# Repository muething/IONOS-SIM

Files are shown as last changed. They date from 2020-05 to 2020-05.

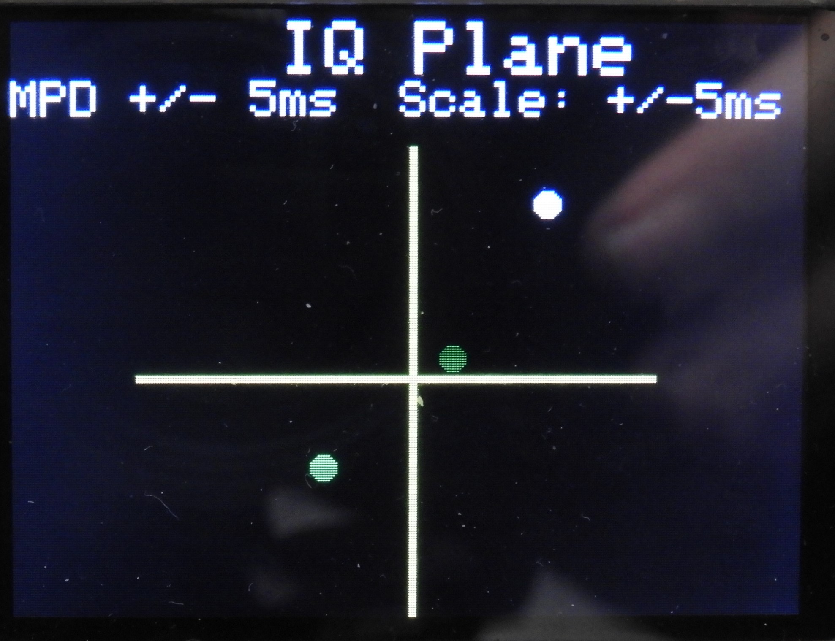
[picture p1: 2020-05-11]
IONOS_SIM_Channel_Simulator/Support Docs/DSCN1394.jpg

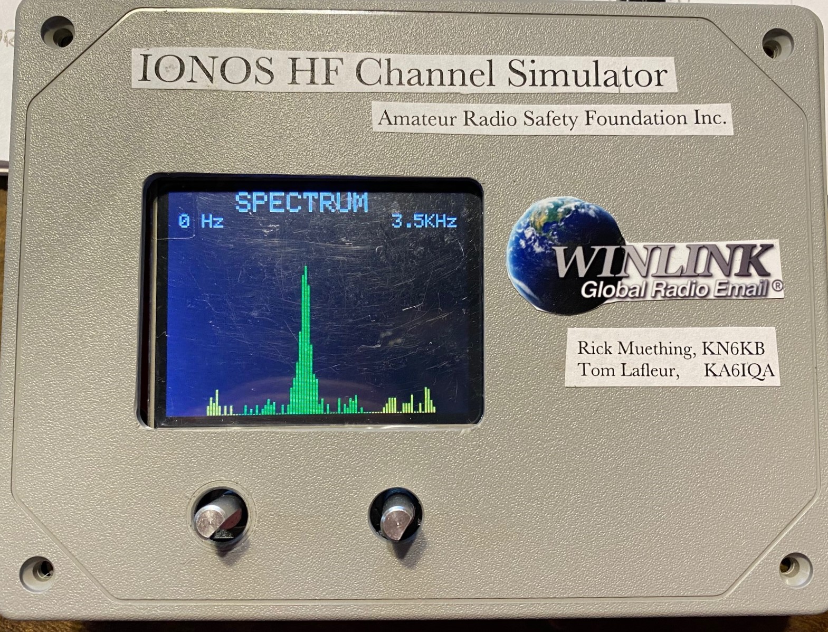
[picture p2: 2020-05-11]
IONOS_SIM_Channel_Simulator/Support Docs/Rev2Protype.jpg

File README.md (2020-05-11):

# IONOS-SIM
IONOS SIM HF/VHF Simulator
This project Implements an Audio based HF or VHF/UHF Ionospheric Propogation Channel Simulator. It is based on the common Waterson model
and is implemented using the Teensy 4.0 microprocessor ( www.prjc.com ). The simulator uses support chips for audio processing and  
user interface components.  It makes extensive use of the Teensy Audio Library for many DSP functions. The Simulator can be used to
simulate (using audio from modems or sound cards) propagation using 5 Different HF channels and 3 Different VHF Channel types. 
The software for the Teensy is released under the MIT Open Source Initiative.  The documentation includes Power Point slides of the 
simulator and how it is used, the full specifications of the simulator, and a basic setup and operating guide. The Project was developed
with the support of the Amateur Radio Safety Foundation Inc a Florida 501C3 non profit corportion and the Winlink Radio Email system. 
Developers: Rick Muething, KN6KB: Tom Lafleur, KA6IQA; and Tom Whiteside, N5TW.

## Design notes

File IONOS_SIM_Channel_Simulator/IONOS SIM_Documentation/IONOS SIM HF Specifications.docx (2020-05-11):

IONOS SIM HF/VHF Channel Simulator Specifications

Rev 1.1 April 15, 2020

Rick Muething KN6KB, Tom Lafleur KA6IQA, Winlink Development Team

Description: IONOS SIM is a self-contained audio DSP based ionospheric simulator based on the Watterson Model [1] for standardized HF and VHF propagation paths. It uses the Teensy 4.0 CPU (ARM Cortex-M7 processor at 600 MHz) and Teensy Audio DSP Library.

Primary Use: The development, characterization, maintenance and comparison of HF and VHF modems and protocols including “sound card” protocols.

Channels Modeled: WGN (White Gaussian Noise: Spread 0 Hz, Delay:0 MS); , MPG (CCIR Multipath Good) Spread .1 Hz, Delay .5ms ; MPM (CCIR Multipath Moderate) Spread .5Hz, Delay 1ms; , MPP (CCIR Multipath Poor) Spread 1 Hz, Delay 2ms; MPD (Multipath disturbed) Spread 2.5 Hz, Delay 5 MS; Flat Fading 0-40 dB Fade, variable rate; Fixed Freq offset +/- 200 Hz; Slow FM deviation +/- 100 Hz, Rate .1 to 100 Hz. Multipath Delay update rate 40x spread.

Audio Paths: WGN: 1 path. Multipath: 2 channels, each with I and Q (4 total rays). Input to Output Delay: Min 3ms (WGN); Max 15 MS (Multipath Disturbed).

Connections Modeled: 1 Simulator: Half duplex, both sides, symmetric channel models. 2 Simulators: Full Duplex both sides: symmetric or asymmetric channel models.

Bandwidths: .1 to 3.3 KHz, .1 to 6.3 KHz. Ripple < 1dB Sampling rate: 44.1 KHz

Noise modeling: WGN filtered to 3 KHz or 6 KHz bandwidth. S:N -40 to +40 dB, 1 dB steps.

Inputs: Ch1, Ch2 via standard Stereo 1/8” (3..5 mm) jack. AC coupled. Input protection. Impedance > 50KOhms. Nominal range: 20 – 2000 mv p-p.

Outputs: Ch1, Ch2 via standard Stereo 1/8” (3.5 mm) jack. AC Coupled. Short circuit protection. Impedance 150 Ohms. Nominal range 100-2000 mv p-p.

Power Required: Nominal 5 v (internally reg. to 3.3 V) via micro USB connector. < 200 ma.

Display: 320 x 240 pixel color TFT for Text and Graphics.

Modes: Self-Test and Calibration verification, Setup modes and parameters, Spectrum Display 3 & 6 KHz, Multipath IQ plot.

User Parameter and control: Two Incremental encoders (Mode, Parameter) each with push toggle. Optional USB serial ASCII commands for automated operation.

Size: 6.1” (155 mm) L x 4.7” (120 mm) W x 1.4” (36 mm) H (excluding knobs).

Alternate Functions: Integrated Busy Channel Detector (experimental). Uses only serial USB ASCII command interface with host program.

[1] Watterson, C.C., J.R. Juroshek, & W.D. Bensema. 1970 Experimental confirmation of an HF channel model IEEE Transaction of Communication. Technology. Vol COM-18. Pp 792-803 Dec 1970

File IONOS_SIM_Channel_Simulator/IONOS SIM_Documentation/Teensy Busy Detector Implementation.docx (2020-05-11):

Teensy Busy Detector Implementation

Rick Muething, Rev 1, 3/13/2020

1) The busy detector will use the exact same hardware and software (single compile) as the Teensy HF/VHF channel simulator. The Busy detector function will be enabled and controlled by simple USB serial text commands. When in operation the audio path of the busy detector will be modified from the Simulator to reduce latency.
2) The busy detector (at least initially) will be independent of protocol mode and only look for energy within a serial command specified frequency range (300 Hz to 6300 Hz).
3) There will be a mechanism for computing and using a rolling average of FFT bins a specified number of averages. This will allow simple tradeoff of response time (low number of averages) to sensitivity (high number of averages). The typical range will be something like 1 to 50 averages. The tradeoff of course is in response time as each average will take approximately 11 ms. (the time it takes to complete the 1024 bit FFT on the Teensy 4). The baseline noise fluctuation of the FFT computation will reduce by approximately the square root of the number of averages. E.g. 16 averages (about 176 ms) will reduce the noise variation by about 4 x or 12 dB.
4) There will be a simple command to set the upper and lower frequencies of interest. This only needs to be done when there is a change in operational bandwidth…e.g. when switching from a 3KHz wide channel to a 500 Hz wide channel. The bandwidth selected should include any required tuning offsets (either due to remote station transmitter offset or local receiver dial offset).
5) There will be a command that sets the trip level for detection. The detector will look for energy in the selected frequency range that is above the detection threshold level. (after FFT bin averaging). When a detection is found a serial command notice will be sent from the Busy detector to the host indicating a busy detect. At that time a new average will be started and a Non busy detection will not be sent until at least that averaging time is completed and a no busy condition is detected.
6) The busy detector will initially use a Hanning window for FFT to provide the sharpest frequency detection. Alternate windows could be used to trade off detection threshold and bin resolution.

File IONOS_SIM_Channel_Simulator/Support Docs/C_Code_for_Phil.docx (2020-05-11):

C++ Code for Busy Detector For Phil

This Subroutine averages the bins of the FFT. The value 43.0664 below is the Hz per bin computed by taking the FFT sampling rate and dividing it by the size of the FFT. E.g. If the sampling rate were 12000 samples/sec from the sound card and the FFT size was 256 the value would be 12000/256 or 46.875.

// **** Sub AvgFFTBins *********************Status: Confirmed OK 3/25/2020 Rev 7.3.2 *************

void AvgFFTBins(boolean blnInit, float fltKavg, int intLoFHz, int intHiFHz)

// 3/25/2020 Good results for fltKavg = .1, averaging every 20 bins (~220ms)

// 3/26/2020 Improved with using 2x fltKavag on attack or .5x fltKavg on release

{

float fltTemp = 0; int intHiBin = intHiFHz/43.0664; int intLoBin = intLoFHz /43.0664;

float fltAvgBinSum = 0.0;

if (blnInit)//Initialize the average bins

{

for (int i = 1;i <151; i++) //Skip bin 0 (DC component)

{

fltFFT[i] = 4000.0 * fft1024.read(i);

if ((i >= intLoBin)&&(i <=intHiBin)){fltAvgBinSum += fltFFT[i];}

}

fltAvgBinsOfInt = fltAvgBinSum/(1 + intHiBin - intLoBin);//Initialize fltAvgBinsOfInt on first call with blnInit = true

return;

}

else//Average in new values with fast attack, slow release Rolling Avg Filter

{

for (int i = 1; i < 151; i++)// Modified 3/26/2020 to use fast attack slow release Rolling Avg Filter

// This definitely helps by "holding" the busy condition for a while following an indication.

{

fltTemp = 4000.0 * fft1024.read(i);

if ((i > intHiBin) || (i < intLoBin))

{//Normal = attack and release for bins outside the band of interest

fltFFT[i] = ((1.0 -( fltKavg)) * fltFFT[i]) + ( fltKavg * fltTemp);

}

else if (fltTemp > fltFFT[i])//Faster attack using 2x fltKavg

{

fltFFT[i] = ((1.0 -(2* fltKavg)) * fltFFT[i]) + (2 * fltKavg * fltTemp);

}

else // Slower release using .5x fltKavavg

{

fltFFT[i] = ((1.0 - (.2 *fltKavg)) * fltFFT[i]) + (.2 * fltKavg * fltTemp);

}

}

return;

}

}/// End Sub AvgFFTBins **********************************************************************

Subroutine SearchRatioDetect This Function searches for the largest and smalles group of FFT bins of intSearchWidthHz bins looking for bins above intThreshdB

//******** Sub SearchRatioDetect*************Status: Works well for both narrow and wide band signal detection...Still optimizing********

int SearchRatioDetect(int intLowFHz, int intHiFHz, int intSearchWidthHz, int intThreshdB)

{

int intLowBin = round(intLowFHz/43.0664);int intHiBin= round(intHiFHz/43.0664);

int intSearchWidthBins = round(intSearchWidthHz/43.0664); int intMaxS_NdB;int intIatMax =0; int intIatMin = 0; int intMinS_NdB;

float fltMaxDetect = 0.0; float fltSearchSum = 0.0; float fltSearchSumMax =0.0; float fltSearchSumMin = 1000000;

float fltHi_LowSum = 0.0; float fltDenom = 0.0; float fltNum = 0.0; float fltMaxSN =0;

// Search for largest AND smallest "intSearchWidthHz" signal (between intLowBin and intHighBin inclusive)

for (int i=intLowBin; i<= (intHiBin); i++)

{

fltHi_LowSum = fltHi_LowSum + fltFFT[i];//Sums all the bins between intLowBin and intHighBin inclusive

if (i <= (intHiBin - intSearchWidthBins)) //This bounds the search to the region of interest

{

fltSearchSum = 0;// Search for the max and min contiguous bins of width intSearchWidthBins

for (int j= 0;j <intSearchWidthBins; j++)

{

fltSearchSum += fltFFT[i + j];// Sum all the bins within intSearchWidthBins

}

if (fltSearchSum > fltSearchSumMax)

{

fltSearchSumMax = fltSearchSum;//The max sum found in a range of intSearchWidth

intIatMax = i;

}

if (fltSearchSum < fltSearchSumMin)

{

fltSearchSumMin = fltSearchSum; //The minimum sum found in a range of intSearchWidth

intIatMin = i;

}

}

}

// Generate Numerator and Denominator normalized to per bin for the Highest S:N

fltDenom =(fltHi_LowSum -fltSearchSumMax)/((intHiBin- intLowBin)-intSearchWidthBins);//Avg energy/bin outside region of max

fltNum = fltSearchSumMax/intSearchWidthBins;//Maximum Energy per bin over intSearchWidthHz between intLowBin and intHighBin

intMaxS_NdB = round(20*log10(fltNum/fltDenom));

if (intMaxS_NdB >= intThreshdB)//This trips detector when a narrow band peak is found

{

blnPlotBusyRed = true;

return intMaxS_NdB;

}

// Generate the Numerator and Denominator normalized to per bin for the Lowest S:N

fltDenom = (fltHi_LowSum - fltSearchSumMin)/((intHiBin- intLowBin)-intSearchWidthBins);//Avg energy/bin outside region of max

fltNum = fltSearchSumMin/intSearchWidthBins;//Minimum Energy per bin over intSearchWidthHz between intLowBin and intHighBin

intMinS_NdB = round(20*log10(fltNum/fltDenom));//Typically -3 to -10

if ((intMaxS_NdB - intMinS_NdB) >= (2 * intThreshdB))//This trips the detector when a narrow band minimum is found

{

blnPlotBusyRed = true;

//Serial.print("MaxS_N=");Serial.print(intMaxS_NdB);Serial.print(" MinS_N=");Serial.println(intMinS_NdB);

return (intMaxS_NdB - intMinS_NdB);

}

else if (intMinS_NdB <= (intThreshdB -2))//Only clear the busy condition when intMinS_NdB is 2 dB or more BELOW threshold

{

blnPlotBusyRed = false;

return 0;

}

else return intMaxS_NdB;

}//End************* SearchRatioDetect *********************************************************

Calling code for the prior two subroutines:

if (fft1024.available()) This is Teensy code that says the FFT (in this case 1024 samples of 44.1KHz sample rate or ~43 Hz/bin has been computed and is available

{

AvgFFTBins((intBinsAveraged == 0), .2 ,intBusyBWLoHz,intBusyBWHiHz);//Average the fltFFT[] bins, initialize if intBinsAveraged == 0

intBinsAveraged +=1;

if (intBinsAveraged > intAvg)//If enough averages completed

{

intDetectSN = SearchRatioDetect(intBusyBWLoHz, intBusyBWHiHz, 258, intThresh);//Search and detect Region of Interest for 258 Hz BW)

if ((intDetectSN >= intThresh ) && (!blnChanBusySent) && blnEnbBusyDetect)

{

Serial.print("DETECT:"); Serial.println(intDetectSN);

blnChanBusySent = true;

blnChanClearSent = false;

}

else if ((intDetectSN == 0) && (!blnChanClearSent) && blnEnbBusyDetect)

{

Serial.println("DETECT:0");

blnChanClearSent = true;

blnChanBusySent = false;

}

}

if (0 == (intBinsAveraged % intAvg))// Only plot every intAvg averages (about 11ms /average)

{

if (blnPlotSpectrum)

{

PlotSpectrum(fltFFT,intBusyBWLoHz,intBusyBWHiHz,blnInitSpectrum,intBandwidth);

blnInitSpectrum = false;// only init on first call to print headers.

//Typical time for 20 bin averages ~ 220 ms

//Serial.print("Time to avg 20 bins: ");Serial.println(millis() - ulngLastSpectrumUpdate);

ulngLastSpectrumUpdate = millis();

}

if (intBinsAveraged > 100000){intBinsAveraged = 0;}//To prevent overflow of intBinsAveraged

}

}

}

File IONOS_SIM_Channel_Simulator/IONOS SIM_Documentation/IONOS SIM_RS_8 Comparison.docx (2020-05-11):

Comparisons between the IONOS HF/VHF Sim and the RS-8 HF & V/UHF Channel simulators

FEATURE IONOS SIM HF/VHF RS-8 HF & V/UHF

Independent settings 1 shared by Ch1, Ch2 2 Left, Right

Bandwidth 3KHz, 6KHz, 3KHz, 6KHz

S:N Adjust -40 to +40 dB, 1dB steps -63, +63 dB, .5 dB steps

Number of HF Paths: 1, or 4 1, 2, 3, 4, or 5

VHF Paths 1, Fade, Offset, Doppler Sweep 1-6 Delay, Doppler, Power

Channel Types Preset: WGN, MPG, MPM Variable: all parameters MPP, MPD, FLAT FADE settable Paths 2-5

Display Internal Color text, Spectrum, IQ Monochrome Text, Graphics with PC

User Controls: 2 multi-function Encoders, USB Serial Front panel buttons, PC Graphics.

Interference none 4: fixed CW, swept CW, FSK, Narrow Generators

Discussion: Basically, there are five major differences:

1) THE IONOS SIM has only one setting it can share that setting with 2 Half duplex channels with the same channel modeling. Full duplex or independent paths requires two IONOS SIMs. The RS-8 can do independent channels and full duplex by itself with one simulator.
2) IONOS SIM uses preset CCIR defined channels (except for MPD). The RS-8 allows independent setting of all channel parameters allowing full flexibility of setting any desired channel.
3) The RS-8 has 4 programmable “interference generators” that adds an interference signal into the band of interest.
4) The Manual and specification for the IONOS Sim is 12 pages, the RS-8 is 120 pages.
5) The RS-8 costs about 40x the IONOS SIM ($8000/$200)

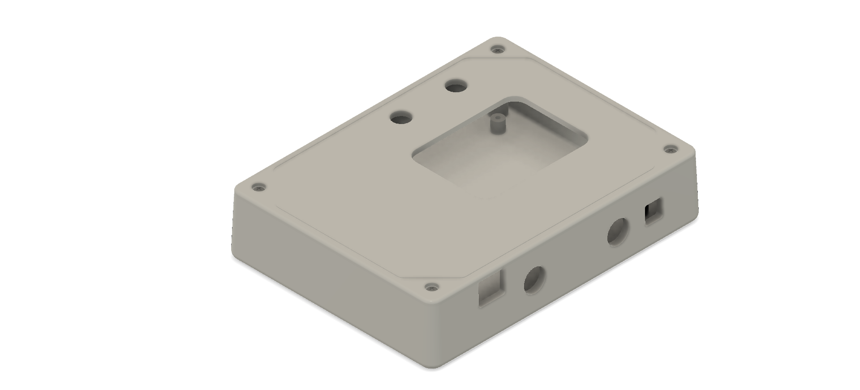
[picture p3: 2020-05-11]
IONOS_SIM_Channel_Simulator/IONOS SIM_Documentation/Lafleur_DC-45PMBYT_ASS'Y v5.png

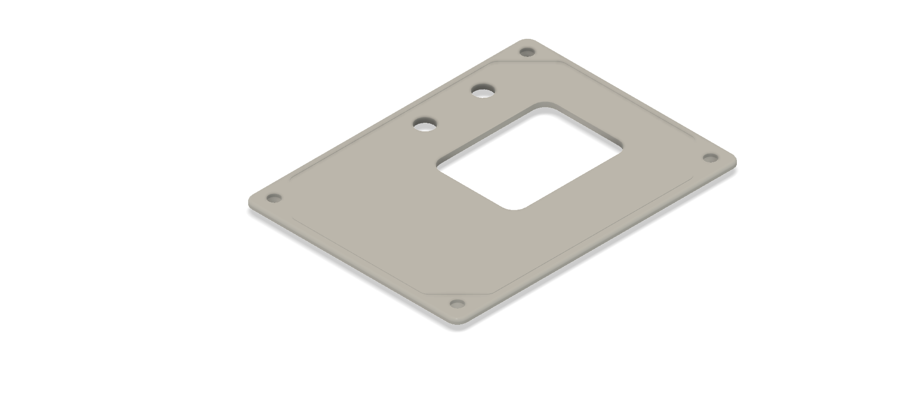
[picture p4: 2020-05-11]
IONOS_SIM_Channel_Simulator/IONOS SIM_Documentation/Lafleur_DC-45PMBYT_ASS'Y v5lidonly.png

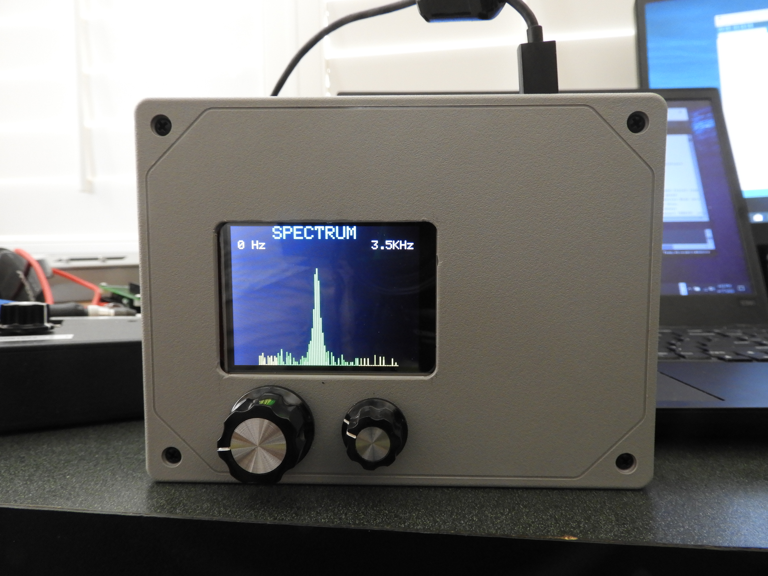
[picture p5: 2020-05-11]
IONOS_SIM_Channel_Simulator/Support Docs/Rev2Protype_2.JPG

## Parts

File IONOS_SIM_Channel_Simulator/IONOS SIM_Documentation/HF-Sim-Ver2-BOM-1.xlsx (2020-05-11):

Winlink HF Simulator Ver 2a/2b
 |  | As Built
Device | QTY | QTY | Value | Note | Pkg | Mfg | Mfg | Cost | Total | Most small parts are priced at 100 each
 |  |  |  |  |  | Part Number |  | (100's)
C1, C9, C11, C12, C13, C18 | 6 | 6 | 0.1uf | X5R, X7R, 50V | 0805 | C0805C104M5RACTU | Kemet | 0.05 | 0.30 |  | Substitute parts ok
C14 | 1 | 1 | .15uf | X5R, X7R, 50V | 0805 | CC0805KRX7R9BB154 | Yageo | 0.07 | 0.07 |  | Substitute parts ok
C3, C4, C5, C6, C7, C8 | 6 | 6 | .01uf | X5R, X7R, 50V | 0805 | C0805C103J5RAC7210 | Kemet | 0.05 | 0.30 |  | Substitute parts ok
C2, C11, C19, C24, C17 | 5 | 3 | 10uf | X5R, X7R, 16V | 0805 | C0805C106K4PACTU | Kemet | 0.07 | 0.21 | C19, C24 Not Installed | Substitute parts ok
C15, C16, C23, C22, C20, C21 | 6 | 6 | 2.2uf | X5R, X7R, 16V | 0805 | CC0805KRX5R7BB225 | Yageo | 0.08 | 0.48
 |  |  |  |  |  |  |  |  | 0.00
 |  |  |  |  |  |  |  |  | 0.00
R1, R2, R3, R4 | 4 | 4 | 1.2k |  | 0805 | RC0805FR-071K2L | Yageo | 0.02 | 0.08 |  | Substitute parts ok
R5, R6 | 2 | 2 | 4.7k |  | 0805 | RC0805FR-074K7L | Yageo | 0.02 | 0.04 |  | Substitute parts ok
R7, R8, R9, R10, R11, R12, R13, R14, R22, R37, R29 | 11 | 8 | 10k |  | 0805 | RC0805FR-0710KL | Yageo | 0.02 | 0.16 | R22, R29, R37 Not Installed | Substitute parts ok
 |  |  |  |  |  |  |  |  |  |  | Substitute parts ok
R20, R30, R31, R15, R16, R17, R18, R19 | 8 | 8 | 120 Ohms |  | 0805 | RC0805FR-07120RL | Yageo | 0.02 | 0.16 |  | Substitute parts ok
R23 | 1 | 0 | 240 Ohms |  | 0805 | RC0805FR-07240RL | Yageo | 0.02 | 0.00 | Not Installed | Substitute parts ok
R21 | 1 | 0 | 470 Ohms |  | 0805 | RC0805FR-07470RL | Yageo | 0.02 | 0.00 | Not Installed | Substitute parts ok
R27, R35, R25, R28 | 4 | 4 | 100k |  | 0805 | RC0805FR-07100KL | Yageo | 0.02 | 0.08 |  | Substitute parts ok
R32, R24 | 2 | 2 | 0 Ohms | ( 4.2k) | 0805 | RC0805FR-070RL | Yageo | 0.02 | 0.04 |  | Substitute parts ok
R26, R34 | 2 | 2 | 1k |  | 0805 | RC0805FR-071KL | Yageo | 0.02 | 0.04 |  | Substitute parts ok
 |  |  |  |  |  |  |  |  | 0.00
Q1 | 1 | 0 | IRLML6244TR |  | SOT-23 | IRLML6244TRPBF | Infineon | 0.18 | 0.00 | Not Installed
 |  |  |  |  |  |  |  |  | 0.00
 |  |  |  |  |  |  |  |  | 0.00
L1, L2, L3 | 3 | 1 | 1K @100 MHz |  | 0805 | BK2125HS102-T | Taiyo Yuden | 0.40 | 0.40 | L2, L3 Not Installed
 |  |  |  |  |  |  |  |  | 0.00
U1 | 1 | 1 | Teensy 4.0 | Processor |  |  |  | 22.00 | 22.00 | Not Installed
U2, U3 | 2 | 2 | PEC11R-4230F-S0024 | Encoder |  | PEC11R-4230F-S0024 | Bourns | 1.56 | 3.12
U4 | 1 | 1 | AP7313-18SAG | 1.8v LDO | SOT-23 | AP7313-18SAG-7 | Diode Inc | 0.19 | 0.19
U5 | 1 | 1 | SGTL5000 | Audio Codex | QFN32 | SGTL5000XNNA3 | NXP | 3.03 | 3.03
U6 | 1 | 0 | PVT312LSPBF | SS Relay | 6-SMD | PVT312LSPBF | NXP | 2.84 | 0.00 | Not Installed
U7 | 1 | 1 | OPA2322AID | Dual Op-Amp | 8-MSOP | OPA2322AID | TI | 1.49 | 1.49
 |  |  |  |  |  |  |  |  | 0.00
J1 | 1 | 0 | P02EK381V2 | Wire Connector, 2 pin |  | P02EK381V2 | Kobiconn | 0.49 | 0.00 | Not Installed
J2, J3 | 2 | 2 | STX-3120-3B | 1/8 in Stero Audio Jack |  | STX-3120-3B | Kycon | 0.49 | 0.98
 |  |  |  |  |  |  |  |  | 0.00
P1 | 1 | 0 | 4 pin, .1in Male Pins | Male Pins | 2.54mm |  |  | 0.68 | 0.00 | Not Installed
P2 | 1 | 1 | 14 pin, .1in header | 7mm tall | 2.54mm | 1-215297-4 | TE-AMP | 1.52 | 1.52 |  | Alt Parts | Amphenol | 76341-314LF
P3 | 1 | 0 | 9 pin, .1in header | 7mm tall | 2.54mm | 215297-9 | TE-AMP | 1.24 | 0.00 | Not Installed | Alt Parts | Amphenol | 76341-309LF
P4 | 1 | 1 | 5 pin, .1in header | 7mm tall | 2.54mm | 215297-5 | TE-AMP | 0.90 | 0.90 |  | Alt Parts | Amphenol | 76341-305LF
 |  |  |  |  |  |  |  |  | 0.00
U1 Socket for Teensy 4.0 | 2 | 2 | 14 pin, .1in header | 7mm tall | 2.54mm | 1-215297-4 | TE-AMP | 0.68 | 1.36 |  | Alt Parts | Amphenol | 76341-314LF
 |  |  |  |  |  |  |  |  | 0.00
D1, D2, D4 | 3 | 3 | LED Amber |  | 0805 | LTST-C171AKT | Lite-On | 0.08 | 0.24
D3 | 1 | 1 | Led Green |  | 0805 | LTST-C171KGKT | Lite-On | 0.08 | 0.08
 |  |  |  |  |  |  |  |  | 0.00
 | 2 | 2 | Knob, .250 Shaft |  |  |  |  | 3.00 | 6.00 | Not Installed
 | 1 | 1 | Case, Poly | Case, Smooth Top, Gray |  | DC-45PMBYT*01 | PolyCase | 22.00 | 22.00 | Not Installed
 | 4 | 4 | Case PCB, Screws | 4/24, 3/8 in |  |  |  | 0.02 | 0.08 | Not Installed
PCB | 1 | 1 | Circuit Board |  |  |  |  | 4.00 | 4.00
LCD | 1 | 1 | 2.8in LCD-Touch | 320x240, Touch Panel |  | MSP2807 | China | 6.00 | 6.00 | Not Installed | Alt Parts | MSP2806 No Touch
 |  |  |  |  |  |  |  |  | 0.00
 |  |  |  |  |  |  |  | Total: | 75.35
 |  |  |  | Alt Parts
 |  |  |  | 47uf 10v 0805 X5R |  | GRM21BR61A476ME15L | Murata | 0.37
 |  |  |  | 22uf 10v 0805 X5R |  | GRM21BR61A226ME51L | Murata | 0.15

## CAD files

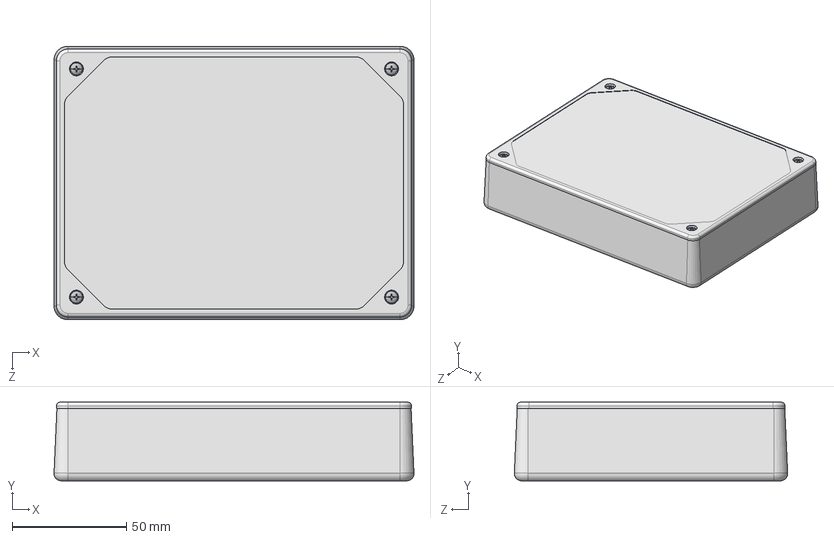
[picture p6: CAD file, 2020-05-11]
IONOS_SIM_Channel_Simulator/DC-45PMBYR_ASS'Y.STEP
157.9 x 34.5 x 119.9 mm
SCREWS-DC-BR x 4
DC-45B_DC-45BPMBY
DC-46C_DC-46C-R

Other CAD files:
IONOS_SIM_Channel_Simulator/IONOS SIM_Documentation/Lafleur_DC-45PMBYT_ASS'Y v7.step
IONOS_SIM_Channel_Simulator/DC-45PMBYT_ASS'Y.STEP

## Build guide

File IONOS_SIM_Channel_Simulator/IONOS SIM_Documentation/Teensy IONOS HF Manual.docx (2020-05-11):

IONOS SIM HF/VHF Channel Simulator

BUSY DETECT Busy Channel Detector

Instructions, Basic Documentation, and Specifications

Ref: Software Beta revision 0.9.14 Rick Muething, KN6KB May 8, 2020

1.0 Introduction: The Teensy IONOS SIM is an audio processing 1-4 path (ray) simulator that models standard HF and VHF propagation channels. It is intended primarily for modem and protocol design, analysis, optimization and comparison. It allows non-radio testing of protocols and modems using statistically standardized channels that would be almost impossible to achieve with normal “over the air” RF testing. The simulator is based on the well-documented Watterson model [ 1] used by many laboratory grade instruments costing many thousands of dollars.

2.0 Basic Description: The IONOS SIM Simulator is based on the low-cost but powerful Teensy 4.0 processor (https://www.pjrc.com/store/teensy40.html) and was developed using the Arduino platform and makes extensive use of the Teensy Audio DSP library https://www.pjrc.com/teensy/gui/index.html . The IONOS SIM software is released under the MIT Open Source License (see appendix). A simplified block diagram of the simulator is shown below in Fig 1.

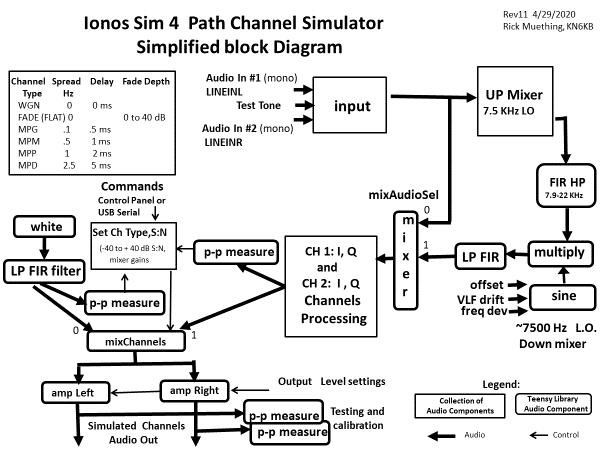
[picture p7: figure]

Fig 1. Teensy IONOS HF/VHF Channel Simulator block diagram.

[1] Watterson, C.C., J.R. Juroshek, & W.D. Bensema. 1970 Experimental confirmation of an HF channel model IEEE Transaction of Communication. Technology. Vol COM-18. Pp 792-803 Dec 1970

3.0 Basic Layout: The Basic layout of the Simulator is shown in Figs 2 & 3. The simplified user interface consists of just 2 rotary encoders (each with push switch) and a small color graphics TFT display mounted in an ~ 4” x 6” customized PolyCase enclosure. The simulator is powered through its micro USB connector which also provides optional USB serial I/O for computer- controlled operation if desired. Audio input (2 mono channels) and audio output (2 mono channels) connections are made using standard 1/8” (3.5 mm) stereo phone jacks.

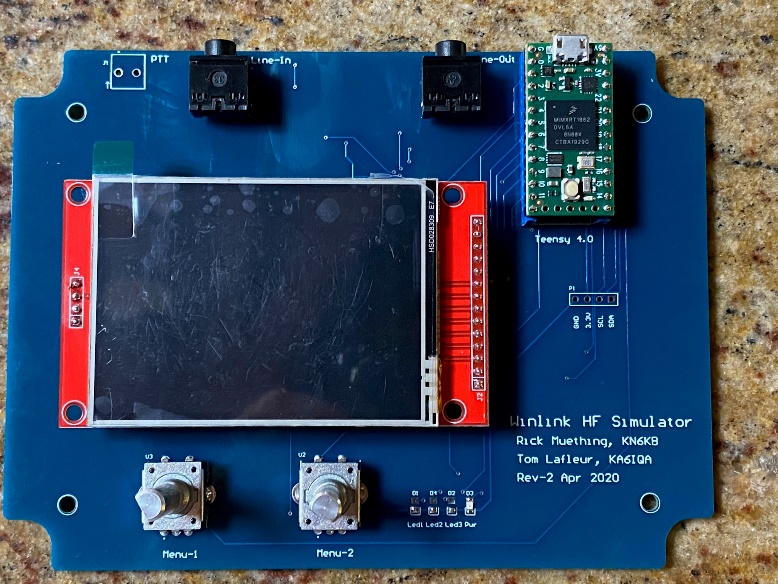
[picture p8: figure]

Fig 2. Basic control/display layout (Rev 2 prototype) Schematic, PCB design, layout assembly and test by Tom Lafleur KA6IQA

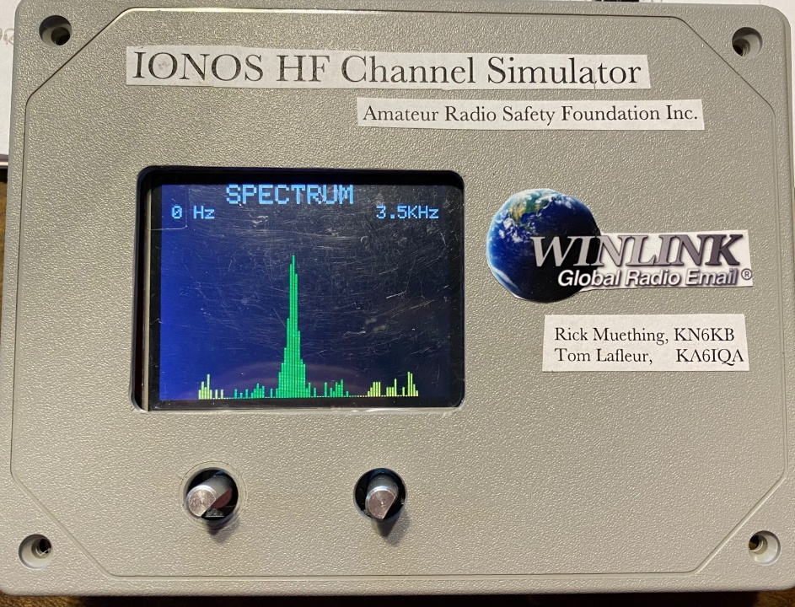
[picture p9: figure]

Fig 3. Revision 2 in Protype Case

3.1 Power on Automated self test. There is a simple mechanism for automated self-test and calibration verification. First connect the output jack to the input jack with a standard Stereo 1/8” (3.5 mm) 3 conductor male patch cord. This jumpers the CH1 and CH2 output amplifiers to the CH1 and CH2 input buffers. The self-test software will block the normal in to out loop to avoid oscillations and accurately measure the response of the precision internally generated test signal and the injection of that signal into the inputs. This verifies: a) Connections and wiring to the output and input jacks, b) proper amplifier resistor values/tolerance, c) proper low frequency coupling capacitors, d) All Teensy Audio processing and DSP FIR filtering, e) Frequency response on both 3KHz and 6KHz bandwidths (Flat +/- .5dB). The self-test is also useful in setting up initial modem output levels.

3.1.1 Running the Self Test. With the patch jumper above in place, power on the IONOS Simulator by plugging in the USB port. The software and self-test software are already loaded. After the power on display of the current code revision (e.g. IONOS SIM 0.9.7 etc.) the display will enter the normal power on mode (WGN mode with S:N = 40 dB). Rotate the Mode (left hand encoder) knob 16 clicks CW to activate the TEST3K Sine: selftest. This will set up a 1548 Hz test sine wave at a specific amplitude and begin averaging the p-p (peak to peak) voltage readings at the input buffers (Ch1 in, Ch2 in) and output Amps (Ch1 Out, Ch2 Out). Averaging is used to increase accuracy and after about 5 seconds the average measurements should stabilize to stable values (all values in p-p mv). If the values displayed are all green text, the measurements are with +/- .5 dB…the basic accuracy of the simulator. Any values in red text are outside the +/- .5 dB limit above. Different levels for Ch1 and Ch2 are used to verify no cross-coupling. The entire range of frequencies for the 3 KHz bandwidth can be tested by rotating the right hand (parameter) knob. Frequency range for the TEST3K will range from 86 Hz to 3182 Hz. During the test you can toggle to the Spectrum display by pushing down on the Mode (left hand) encoder. Pushing again will toggle back to the TEST3K display.

In a similar way rotating the mode knob CW one additional click (17 clicks from Power on WGN position) will enable the TEST6K test. It works exactly the same as the TEST3K but the frequency range spans 172 Hz to 6192 Hz. It exercises different FIR filters used in the 6 KHz bandwidth mode. Again, you may have to wait a few seconds for reading averages to stabilize. The 6 KHz mode swaps the Ch1/Ch2 amplitudes from the 3 KHz test insuring all paths are independent and work at full amplitude.

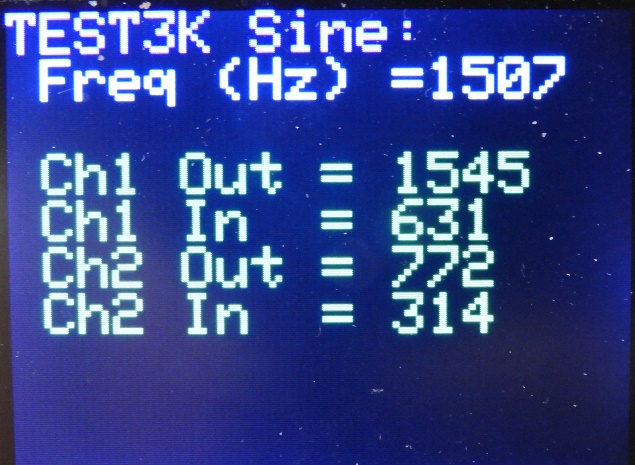
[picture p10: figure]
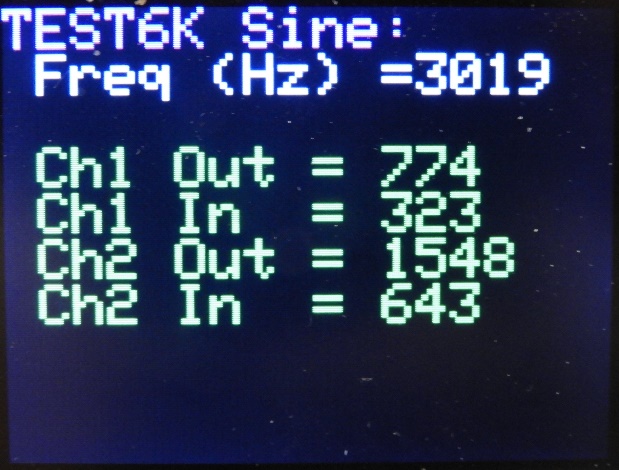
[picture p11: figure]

Fig 4. Example Screens for TEST3K an TEST6K self-test and calibration.

Green text indicates parameter within +/- .5 dB and values can vary about 5% from those shown above.

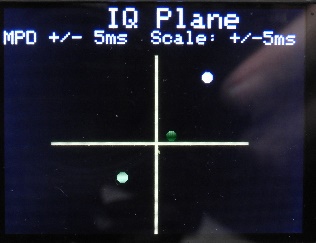
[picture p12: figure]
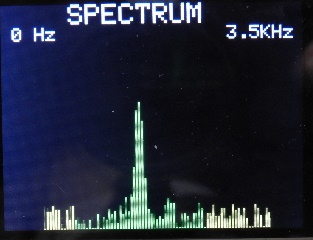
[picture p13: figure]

3.2 Getting Familiar with the controls and displays of IONOS SIM. You can gain familiarity with the simulator without hooking it up to any modems or TNCs. An earphone (mono or stereo) plugged into the Ch1,2 output jack will be helpful. Upon power-up after plugging in to a +5 v powered micro USB port the TFT display will Activate and show IONOS SIM version xxxxx for three seconds before going to the Basic Mode display. There it will show the current mode “WGN:” in blue text and the current parameter value for that mode which will be “S:N= 40 dB” in green text. WGN (White Gaussian Noise) is the most basic mode and one that will be used often for setup and initial testing runs. Rotate the right hand encoder (parameter) CW or CCW to roll through the S:N options (-40 to +40 dB). The display of mode settings/parameters and text colors are similar for the 14 other modes shown in Fig 7. (The self-test modes TEST3K and TEST6K are shown in magenta to distinguish them from normal operating modes) Most modes and settings can be left at their power on defaults for basic testing. For modes WGN-MPP pushing down on the right encoder until it clicks will toggle the internal 1500 Hz test tone on/off. You should hear the tone in the earphone and adjusting the S:N lower should increase the noise. Most people can still hear the signal down to about -10 to -15 dB below the noise (all dB measurements and calculation are based on the operational bandwidth (3000/6000 Hz). In other modes pushing down on the right encoder will save the current mode parameter to EEPROM as the power on default value. For modes WGN-MPD pushing on the left encoder knob should switch the display to the Spectrum mode (3.5 or 6.5 KHz). There you should see the test tone and the background noise (white noise filtered to bandwidth) displayed. The vertical plotting scale of the spectrum analyzer is logarithmic and covers approx. 60 dB dynamic range. Each spectrum line (2 pixels wide for 0 to 3500 Hz) represents one ~43 Hz frequency bin. Toggle off the spectrum display with another push of the mode knob) to return to the Basic Mode display. Now select a multipath mode (say MPP for Multi Path Poor). Push the Mode (left) encoder once to switch back to the spectrum display. There you will see the impact the 4 ray multipath distortion created by the simulator has on the 1500 Hz test tone. MPP is a rather poor channel and HF digital communications on this path are often marginal. Another push of the Mode (left) encoder will toggle to the IQ Plane display. This display shows dynamically how the 4 audio channels (In phase or I and quadrature or Q ) for two audio paths (4 total “rays”) are dynamically altered by the simulator. The display plots white and green “dots” corresponding to the calculated I & Q delay shifts for 4 audio rays on the IQ delay plane. The speed of the update is 32 x the delay spread for the channel modeled which meets the recommendation established by the CCIR. The IQ Plane plot scale remains constant at +/- 5 ms for all multipath modes. The values calculated by the simulator are based on a +/- 1 sigma normal (gaussian) distribution of the modeled channel’s delay spread. Pushing the mode (left) encoder once more should return you to the Basic Mode display. For most parameters (except S:N on WGN-MPD) you can push the parameter (right) knob to set the displayed value as the power on default (stored in EEPROM). You can explore the various other mode and parameter settings. There are no settings that will damage the Simulator but care should be taken when advancing the output volumes (CH1, CH2 OUT) levels which could result in loud levels to some earphones.

3.3 Exploring the other modes and parameters for other testing. While the WGN and Multipath channels are primarily used in HF Path simulation the simulator also supports functions useful in VHF/UHF path simulation. This testing is usually done using the standard WGN channel (across a range of S:N range of interest) modified with functions for VHF/UHF simulation. The primary ones of these are FLAT fade caused by multipath signal reception on FM and FM Deviation caused by transmitter/receiver drift or doppler shift. Figure 7 shows these modes and the parameter range of each. Again the 1500 Hz test tone can be used as a basic signal source and the Spectrum analyzer display to observe these effects just as was done in the basic HF modes. The fixed OFFSET mode can also be used to supply a small (+/- 200 Hz range) frequency offset to the audio input and this is helpful in testing/evaluating the ability of the modem to handle frequency tuning offsets primarily on HF SSB transmission. Finally, the simulator also supports a 6 KHz bandwidth mode. Though not normally used on amateur HF transmissions this can be used in modeling wider band audio channels used on VHF and UHF such as 9600 baud packet or VARA VHF. In 6 KHz bandwidth mode the simulator’s internal FIR filters are all switched to a 6300 Hz range and the Spectrum display is modified to cover the full range 0 to 6500 Hz. In the 6500 Hz spectrum mode each ~43 Hz bin is represented by a one-pixel-wide vertical rectangle spaced by 1 pixel of black.

4.0 Basic Setup and Connections for using the Simulator. The simulator can be used to model the paths for half-duplex or full duplex connections. With its’ internal audio CH1 and CH2 mixing a single IONOS SIM can handle both directions of a half-duplex connection providing symmetric channel modeling (same channel for Modem 1 to Modem 2 and Modem 2 to Modem 1). Figs. 5 and 6 show the basic connections between modems (or sound cards for sound card protocols) and the simulator for both half duplex and full duplex channel modeling.

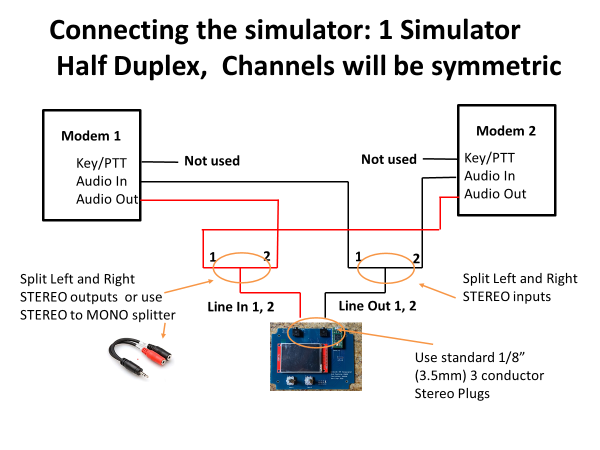
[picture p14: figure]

Fig 5. Basic Half Duplex, symmetric channel setup with one IONOS SIM.

(note: Stereo isolation transformers can be used if ground loops affect audio quality)

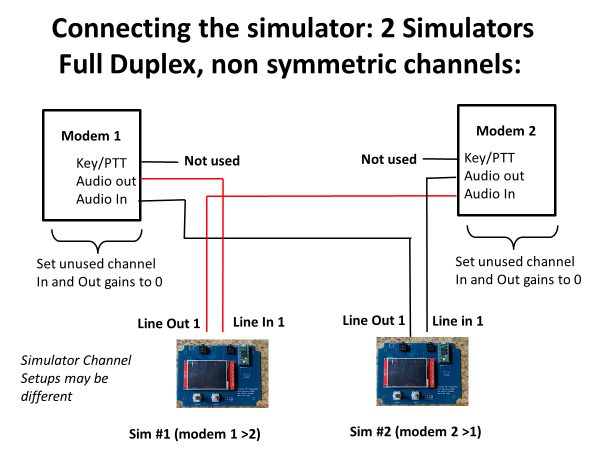
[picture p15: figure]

Fig 6. Full Duplex, non-symmetric channel setup using two IONOS SIMs

(note: Stereo isolation transformers can be used if ground loops affect audio quality)

4.1 Audio Levels. For proper operation the simulator must supply non-saturated, undistorted audio to the modems and receive correct level audio from the modems. The Simulator has 4 audio gain/output level controls that allow a wide independent adjustment for CH1 and CH2 input and CH1 and CH2 Outputs. There are probably also other gain adjustments (hardware or software) on the modem in and out audio. The optimum settings are those output levels that allow modem to be driven with the required signal without overdriving or clipping and with input levels and gain settings that allow the simulator to process audio in its normal range (200 – 1800 mv p-p). Take time to adjust and note the settings [Modems 1 and 2 inputs and outputs, Simulator CH1 and CH2 Inputs and Simulator CH1 and CH2 outputs] so they can be easily setup again. (Simulator gain settings can be saved to EEPROM by pushing on the right (parameter) encoder when the gain setting is displayed). Input gains and output levels are adjustable over a wide logarithmic range (0,.1,.2,.5,1,2,5,10,20,50,100). If an input gain or output level is too large for the dynamic range of the simulator it will cause clipping and distortion of the audio signal. One suggested mechanism for setting the proper level signal into the simulator is:

1)Connect the modem outputs to the simulator. If there is any noise or hum introduced by ground loops using a stereo line isolator (transformer) in the audio to/from the simulator has been shown to help.

2) Set the simulator up for TEST3K mode. This will show the input signal p-p readings on the Ch1 In and Ch2 in lines of the TEST3K display.

3) Adjust the output of the modem to fall within a range of 500 – 1500 (mv p-p) if possible. Operation with inputs at 200 to 1800 mv p-p is the normal minimum to maximum range. The simulator In and Out gain settings can then be used to make simulator output adjustments as desired but care should be used to insure the gain settings selected do not cause saturation of the simulator or the modem.

4) Make test runs using the WGN mode with 10 or 30 dB S:N to verify proper setup and operation before making any extensive measurement runs. Document all the levels used to make repeated setups easier and consistent.

5.0 Manual User Interface. The primary user interface consists of 2 rotary encoders with push capability and a 320x240 pixel color graphics display. The Encoders allow selection of basic Modes (left encoder) and parameters (right encoder). The left push function toggles less used functions on/off : (Spectrum Plot, IQ Plane delay plots). The right encoder push function togles a built in 1.5 KHz oscillator on/off for testing or saves power on default parameter values to EEPROM.

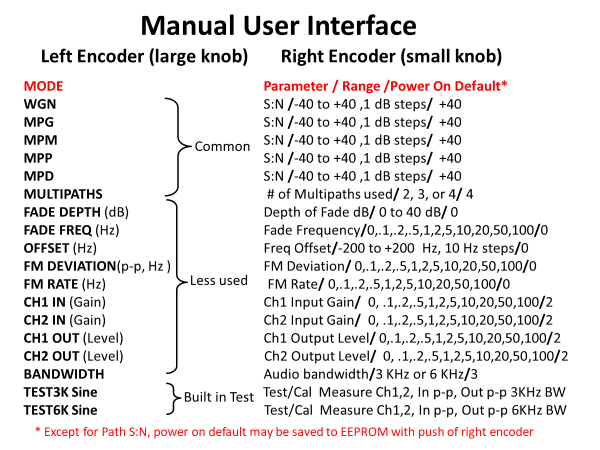
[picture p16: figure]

Fig. 7 . Manual User Interface Encoders 1 and 2.

6.0 Computer interface. Although most users will find the encoder interface above simpler and easier to use an alternative USB serial interface (9600 baud) is included that can allow more sophisticated and automated testing using short ASCII commands through the Simulator’s serial USB port. This will require some user supplied control program that sets up the simulator and modem, runs a session for a specific path type and S:N, and computes and saves performance data (e.g. average net bytes/minute transferred). This can save much time if a large number of simulations are to be run. Each command sent by the computer to the simulator must be sequenced by the correct response [ OK(Cr)] from the simulator. The commands are case insensitive standard ASCII as shown in Fig 8. If a syntax, spelling error, or parameter out of range is received by the simulator a [“?” (Cr)] is returned. The BUSY command is used for a busy detector function (section 7). The commands in Fig 8 correspond to mode and parameter settings of rotary encoders 1 and 2.

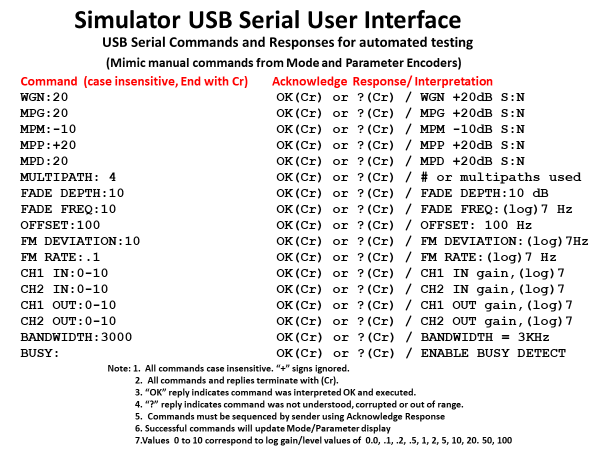
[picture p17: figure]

Fig 8. Serial Commands for Simulator Control

(note: Command “BUSY:”) is normally not used with the Simulator. It switches the IONOS SIM to a BUSY DETECT mode. See section 7.0)

7.0 Basic Application of the Simulator for HF and VHF/UHF use

The use of the IONOS Sim is relatively straight forward but some care is required in setting up test to get consistent and representative test results.

7.1 Test Parameters. Most Simulation runs compare/plot net throughput (after all retries for ARQ modes) vs a specific path type and range of S:N (e.g MPG over +20 to – 10 dB). For comparison several graphs are often shown on one chart. To obtain accurate and repeatable results requires sending sufficient data over a fairly long session (at least 5 minutes and often over 10.). This is because of the nature and designed randomness of the channel modeling and the adaptation to changing channels used by adaptive modems. White Noise and channel delay values are standardized random or normal (gaussian) distributions so successive runs with the same test data and parameter values normally will vary somewhat.

7.2 Test Example for HF Testing of 3 different protocols. Fig 9 below plots the performance in net bytes/minute of 3 HF protocols over a S:N range +40 to -10 dB using a basic WGN (White Gaussian Noise) channel using an early revision of the IONOS SIM simulator. The drop off of throughput vs S:N is normal and gives a good indication of how the protocol can be expected to work at a given received S:N.

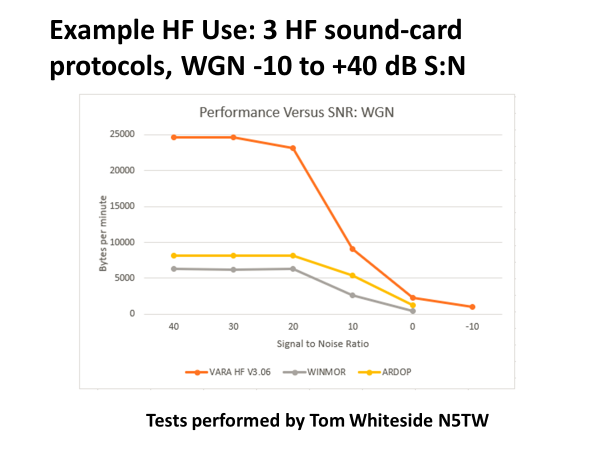
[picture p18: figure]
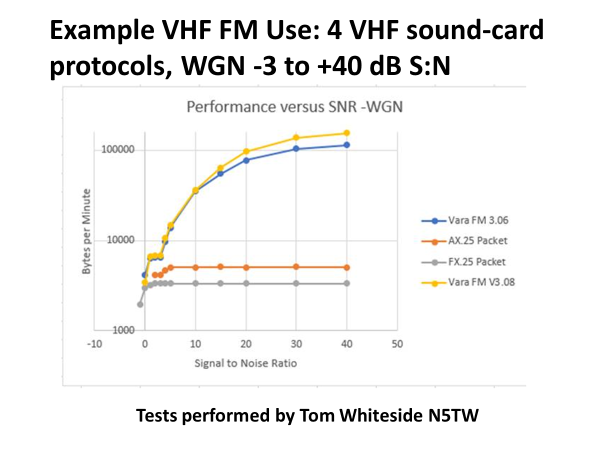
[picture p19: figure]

Fig 9: 3 HF Protocols over +40 to -10 dB S:N Fig 10: 4 VHF Protocols over -3 to + 40 dB S:N

Figure 10 shows a similar simulation for 4 different VHF protocols. Since these protocols can use wider bandwidth “audio” to the FM Modulator the IONOS SIM simulator is set for its 6KHz bandwidth option. These basic simulations then are usually followed by similar sets of curves for different path types. For example for HF modes multipath channels (MPG, MPM, MPP, MPD) can be used over similar S:N ranges to show the affect of multipath propagation. VHF/UHF propagation usually is not modeled with the same multipath but instead often use FLAT FADING channels or FM Deviation which are also supported by the IONOS SIM simulator. Since each plotted “dot” in the above plots represents a typical simulator run of 5 -10 minutes these tests will take some time to complete and log. If extensive testing is anticipated using the computer commands shown in Fig 8 and custom designed simulator and modem control software for setup may be a more efficient use of time and the IONOS SIM simulator. These examples highlight why trying to obtain this kind of test accuracy and repeatability is so difficult using normal “over-the-air” radio testing.

8.0 Busy Channel Detector operation (experimental)

This function rewires (via software) the audio path flow and DSP processing of the IONOS SIM to perform a BUSY DETECT function. The purpose of this function is to provide improved automatic (computer controlled ) busy channel detection capability for automated stations by performing accurate and rapid spectrum analysis over a specified frequency band of interest. This function is in development and optimization of the performance (speed and accuracy) of the busy detector algorithms continues. This function is NOT intended for manual user control so is totally commanded from serial commands sent between the simulator/busy detector from a host computer. Figure 9 summarized the basic commands of the BUSY DETECTOR.

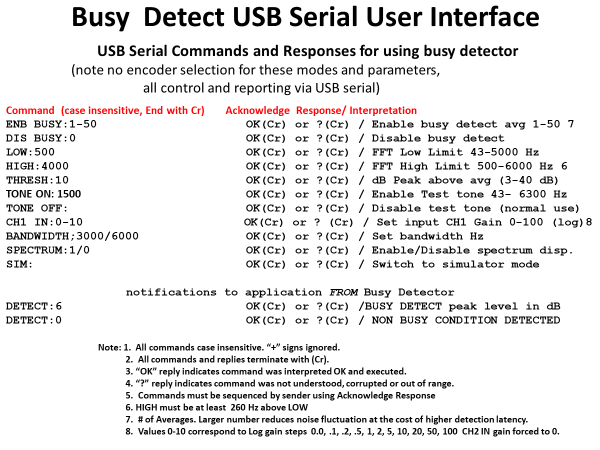
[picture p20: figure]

Fig 11. BUSY DETECT serial commands and responses.

There is one serial command “BUSY: (Cr)” issued from the IONOS SIM serial interface to enter into the BUSY DETECT mode. Once this command is received the screen displays BUSY DETECT and the revision number for 3 seconds and acknowledges by an OK (Cr) response. Then the commands, responses and DETECT: notifications in Fig 9 are operational. Since all operation of the BUSY DETECT function are controlled by serial commands to/from to the host control program there is no encoder mode or manual entry parameters used in BUSY DETECT mode.

8.1 BUSY DETECT Command Details. This section documents the command function use in the busy detector.

ENB BUSY:n 1 <= n <= 50 Enable Busy detection using FFT averages. Each FFT acquisition and average takes approx. 11 ms. This allows trading off noise suppression by averaging (larger number of averages) vs decision time. Typical values range between 10 and 30 averages.

DIS BUSY:0 Disables busy detection

LOW: n 43 Hz <= n <= 5000Hz Sets the low frequency limit for the frequency band of interest.

HIGH: n 500Hz <= n <= 6000 Hz Sets the high frequency limit for frequency band of interest. Note: HIGH value must be at least 260 Hz above LOW value. IMPORTANT: BOTH the HIGH and LOW frequencies should pass to the busy detector without attenuation by any receiver filters. This is easily observed by looking at the spectrum display using the SPECTRUM:1 command. There must be some yellow spectrum lines showing in the spectrum both at the high and low ends of the frequency band of interest. Signals in the yellow spectrum region ARE NOT considered by the busy detect algorithms.

THRESH: 3 to 40 (dB) Sets the detection threshold in dB above the averaged bins. A lower number (more sensitive) will usually require a higher number of averages in ENB BUSY:n above. Each average takes approximately 11 ms so there is a tradeoff in sensitivity vs response time. Typical thresholds are 5-20 dB. With moderate averaging (e.g. 15-20) it should be possible to detect a carrier at approximately -10 to -15 dB below the noise with few false detects. Note this will still be visible on the spectrum display since it displays S+N to N.

TONE ON: n Enable the test tone at frequency n Hz. 43 Hz <= n <= 6300 Hz

TONE OFF: Disable the test tone.

CH1 IN: n Set Input gain on Audio CH1 0 <= n <= 10. This corresponds to a gain factor of 0,.1,.2,.5,1,2,5,10,20,50,100. Audio CH2 Input Gain is forced to 0. Excessive gain will cause clipping and distortion inside the busy channel detector. IMPORTANT: The input level to the busy detector is a function of the audio output of the receiver and the CH1 IN: gain above. It is not critical as long as spectrum lines are showing at the bottom of the display and there is no clipping of the audio level. The Receiver AGC should normally be set to FAST to MEDIUM and the bottom level “grass” of the spectrum on a quiet channel should be set to approximately the lower 25% of the spectrum amplitude.

BANDWIDTH: n Set the Busy detector bandwidth. n = 3000 or 6000 Hz.

SPECTRUM: n Enable (n=1) or Disable (n=0) Spectrum Display. Note on the spectrum display: Signals outside the frequency band of interest (below LOW or above HIGH above) are plotted in yellow. Non-busy conditions will plot the frequency band of interest in green. A busy detection will plot the frequency band of interest in red. Note the spectrum display adds approximately 200 ms to the processing time so the spectrum display should be disabled (SPECTRUM:0) once levels have been set up when operating under computer control.

SIM: Normally not used. Leaves the BUSY DETECT mode and returns to the IONOS SIM mode.

8.2 BUSY DETECT automated responses. There are two automated responses from the BUSY DETECT that are issued automatically upon entering or leaving a channel busy condition. Responses are asynchronous and need not be acknowledged by the Host.

DETECT: n 3 <= n < 40. A busy condition is detected that identifies a signal within the range of LOW to HIGH (above) that is >= the threshold value set with THRESH:n (above). n is in dB. Signals outside the region of interest (LOW TO HIGH) are ignored.

DETECT: 0 Indicates a non-busy condition is detected (after appropriate averaging) There is a small hysteresis used that requires the DETECT:0 to be sent only after the busy detector sense a level 2 dB or more below the programmed THRESH:n level.

8.3 Basic Description of the Busy Detector Algorithm. The busy detector does not try to interpret or in any way decode the signal in the band of interest. That would be a very complex task with significant DSP loading and complex decoding software. It would also limit sensitivity, require continual updating for new modes and significantly lengthen the detection time. Rather the algorithm relies (much like the human ear) on detection of the average energy received in each of the ~43 Hz FFT frequency bins within the spectrum of interest. (Between LOW and HIGH frequencies above). The algorithm averages each of the bins as received (rolling average implemented using IIR filters) to reduce the bin fluctuations due to noise. It then scans the frequency band of interest for narrow (~260Hz wide) peaks or dips in the spectrum lines. This mechanism allows detection of both narrow modes (e.g. CW, RTTY, PSK, JT etc.) and wider modes (e.g. SSB Voice, Pactor, VARA, FAX, WINMOR etc.) By allowing setup via commands (e.g. ENB BUSY:n, THRESH:n, and frequency detection range LOW:n, HIGH:n) the bandwidth, sensitivity and response time can be quickly customized for frequency band and receiver bandwidth during scanning operations. As operating experience is gained improvement in the sensitivity and accuracy of the BUSY DETECT algorithms is anticipated.

IONOS SIM HF/VHF Channel Simulator Specifications Rev 1.8 May 6, 2020

Description: IONOS SIM is a self-contained audio DSP based ionospheric simulator based on the Watterson Model [1]. It uses the Teensy 4.0 CPU (ARM Cortex-M7 processor at 600 MHz) and Teensy Audio DSP Library. The MIT open source licensed software (see appendix) was developed on the Arduino platform.

Primary Use: The development, characterization, maintenance and comparison of HF and VHF modems and protocols including “sound card” modems and protocols.

Channels Modeled: WGN (White Gaussian Noise: Spread 0 Hz, Delay:0ms); , MPG (CCIR Multipath Good) Spread .1 Hz, Delay .5ms ; MPM (CCIR Multipath Moderate) Spread .5Hz, Delay 1ms; , MPP (CCIR Multipath Poor) Spread 1 Hz, Delay 2ms; MPD (Multipath disturbed) Spread 2.5 Hz, Delay 5ms; Flat Fading 0-40 dB Fade, (Rate .1 to 100 Hz); Static Freq offset +/- 200 Hz; Slow FM deviation +/-.1 -100 Hz, FM Rate .1 to 100 Hz. Multipath: (2,3 or 4 channels ) Delay update rate: 32x spread above. (CCIR recommendation)

Audio Paths: WGN: 1 path. Multipath: selectable 2,3 or 4 channels (rays). Input to Output Delay: ~4-16 ms.

Connections Modeled: 1 Simulator: Half duplex, both sides, symmetric channel models. 2 Simulators: Full Duplex both sides: symmetric or asymmetric channel models.

Bandwidths: 3KHzBW:40Hz - 3.3 KHz, 6KHzBW:40Hz - 6.3 KHz. Ripple < +/- .5dB Sampling rate: 44.1 KHz

Noise modeling: WGN filtered to 3 KHz or 6 KHz bandwidth. S:N -40 to +40 dB, 1 dB steps.

Inputs: Ch1, Ch2 via standard Stereo 1/8” (3.5 mm) jack. AC coupled. Input protection. Impedance > 50KOhms. Nominal input range: 200 – 1800 mv p-p.

Outputs: Ch1, Ch2 via standard Stereo 1/8” (3.5 mm) jack. AC Coupled. Short circuit protection. Impedance 150 Ohms. Nominal output range 200-1800 mv p-p.

Power Required: Nominal 5 v (internally reg. to 3.3 V) via micro USB connector. ~ 200 ma.

Display: 320 x 240 pixel color TFT for Text and Graphics. 2.4”x 1.8” (60mm x 45mm)

Operating and Display Modes: Self-test and calibration verification; Set modes and parameters; Spectrum Display (3 & 6 KHz), ~60 dB dynamic range; Multipath dynamic IQ (2,3, or 4 channel) delay plot.

User Parameter and control: Two Incremental encoders (Mode, Parameter) each with push toggle functions. Parameter default values can be saved to EEPROM. USB serial ASCII commands for automated operation.

Size: 6.1” (155 mm) L x 4.7” (120 mm) W x 1.4” (36 mm) H (excluding knobs).

Built In Test: Built in Test (TEST3K, TEST6K) Tests and confirms Input to output continuity, Functions and Calibration accuracy +/- .5 dB in WGN mode across 3000 Hz or 6000 Hz spectrum.

Alternate Functions: Integrated Busy Channel Detector (experimental). Uses only serial USB ASCII command interface with host program.

[1] Watterson, C.C., J.R. Juroshek, & W.D. Bensema. 1970 Experimental confirmation of an HF channel model IEEE Transaction of Communication. Technology. Vol COM-18. Pp 792-803 Dec 1970

APPENDIX:

Copyright (C) 2020 Amateur Radio Safety Foundation Inc. (ARSFI)

Licensed under the MIT Open Source Initiative.

Permission is hereby granted, free of charge, to any person obtaining a copy of this software and associated documentation files (the "Software"), to deal in the Software without restriction, including without limitation the rights to use, copy, modify, merge, publish, distribute, sublicense, and/or sell copies of the Software, and to permit persons to whom the Software is furnished to do so, subject to the following conditions:

The above copyright notice and this permission notice shall be included in all copies or substantial portions of the Software.

THE SOFTWARE IS PROVIDED "AS IS", WITHOUT WARRANTY OF ANY KIND, EXPRESS OR IMPLIED, INCLUDING BUT NOT LIMITED TO THE WARRANTIES OF MERCHANTABILITY, FITNESS FOR A PARTICULAR PURPOSE AND NONINFRINGEMENT. IN NO EVENT SHALL THE AUTHORS OR COPYRIGHT HOLDERS BE LIABLE FOR ANY CLAIM, DAMAGES OR OTHER LIABILITY, WHETHER IN AN ACTION OF CONTRACT, TORT OR OTHERWISE, ARISING FROM, OUT OF OR IN CONNECTION WITH THE SOFTWARE OR THE USE OR OTHER DEALINGS IN THE SOFTWARE.

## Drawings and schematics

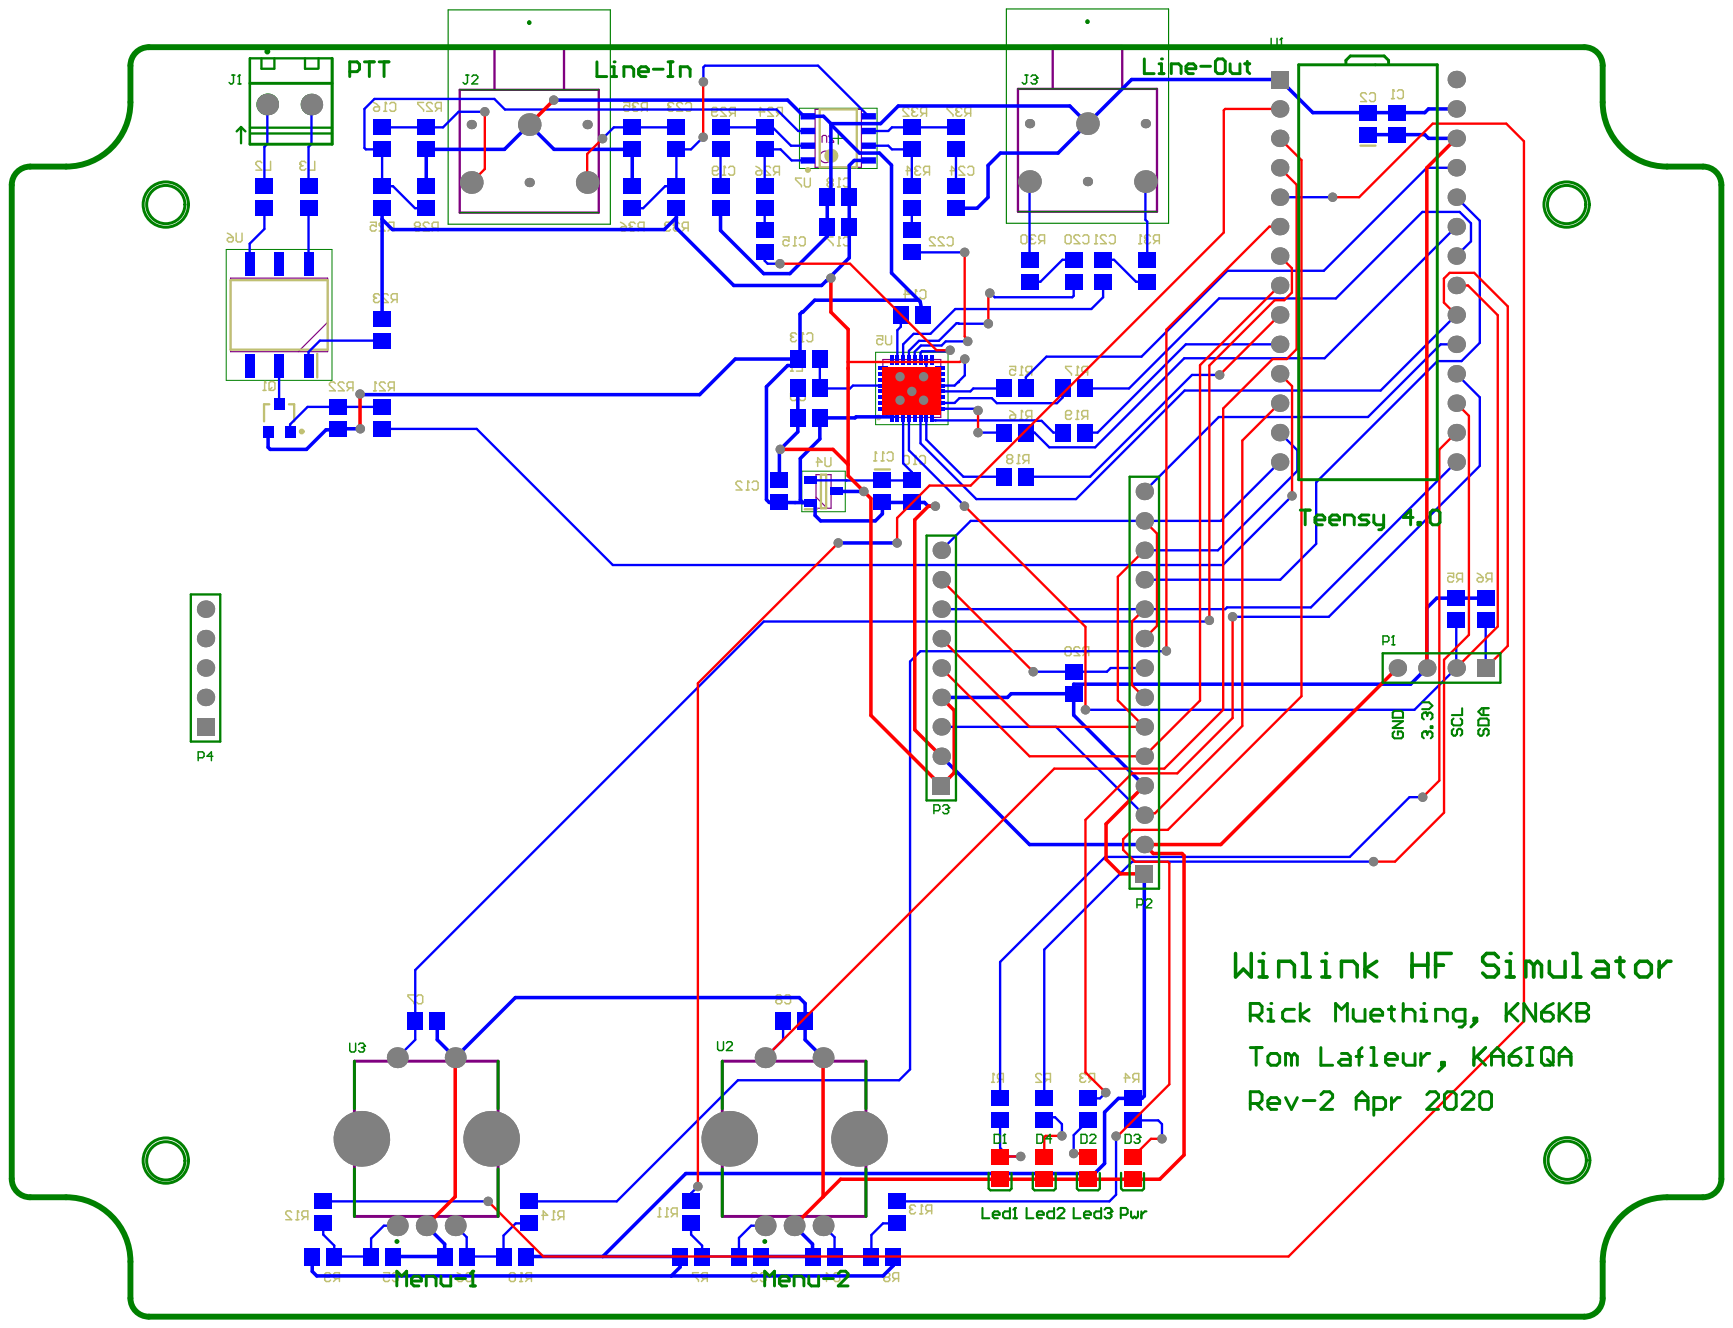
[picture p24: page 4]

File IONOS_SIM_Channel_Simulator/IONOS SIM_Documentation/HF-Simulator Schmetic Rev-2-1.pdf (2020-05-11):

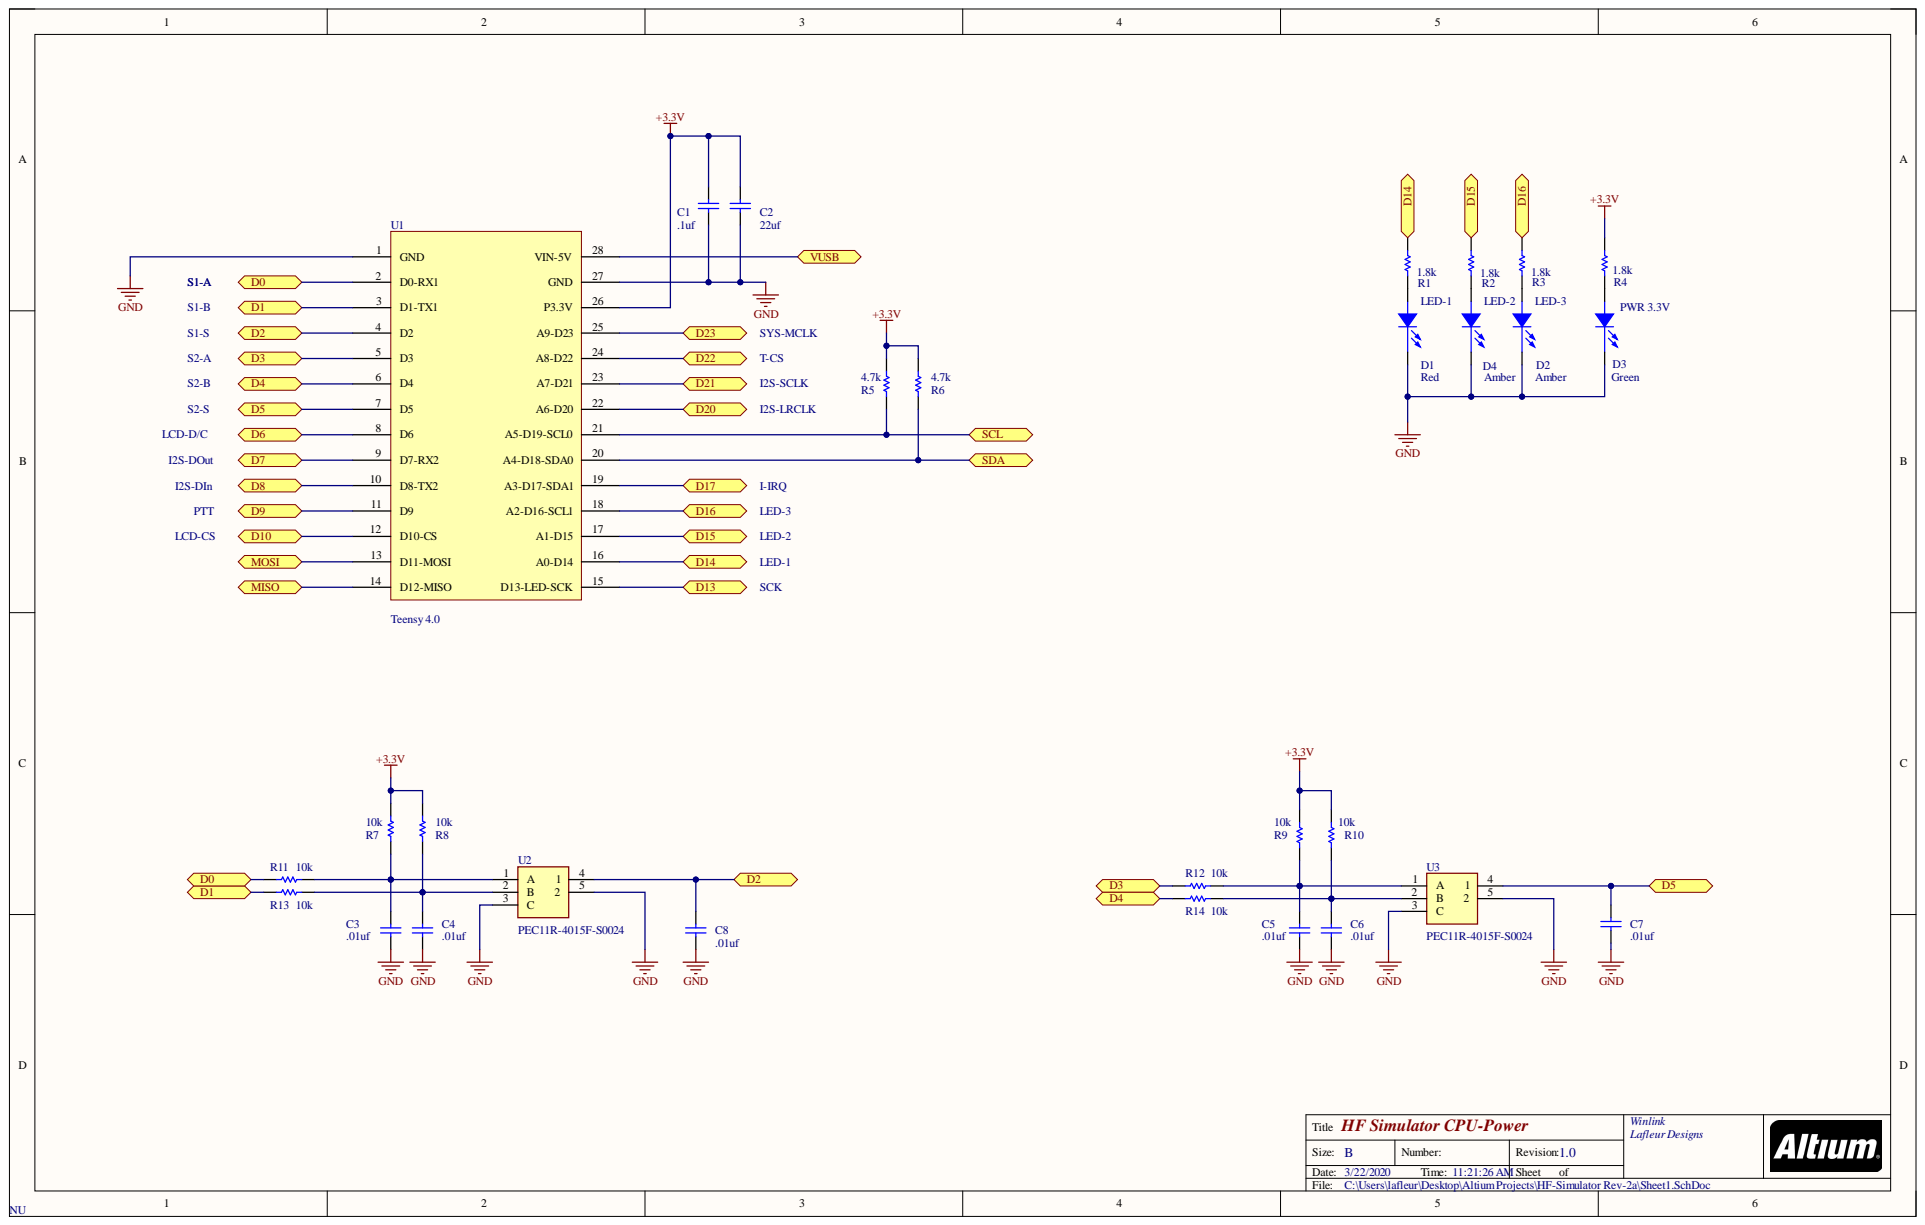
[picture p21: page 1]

Title | Lafleur Designs F Simulator CPU-Power Winlink H

Size: B | Number: | Revision: 1.0
Date: 3/22/2020 Time: 11:21:26 AM | | Sheet of

C:\Users\lafleur\Desktop\AltiumProjects\HF-Simulator Rev-2a\Sheet1.SchDoc

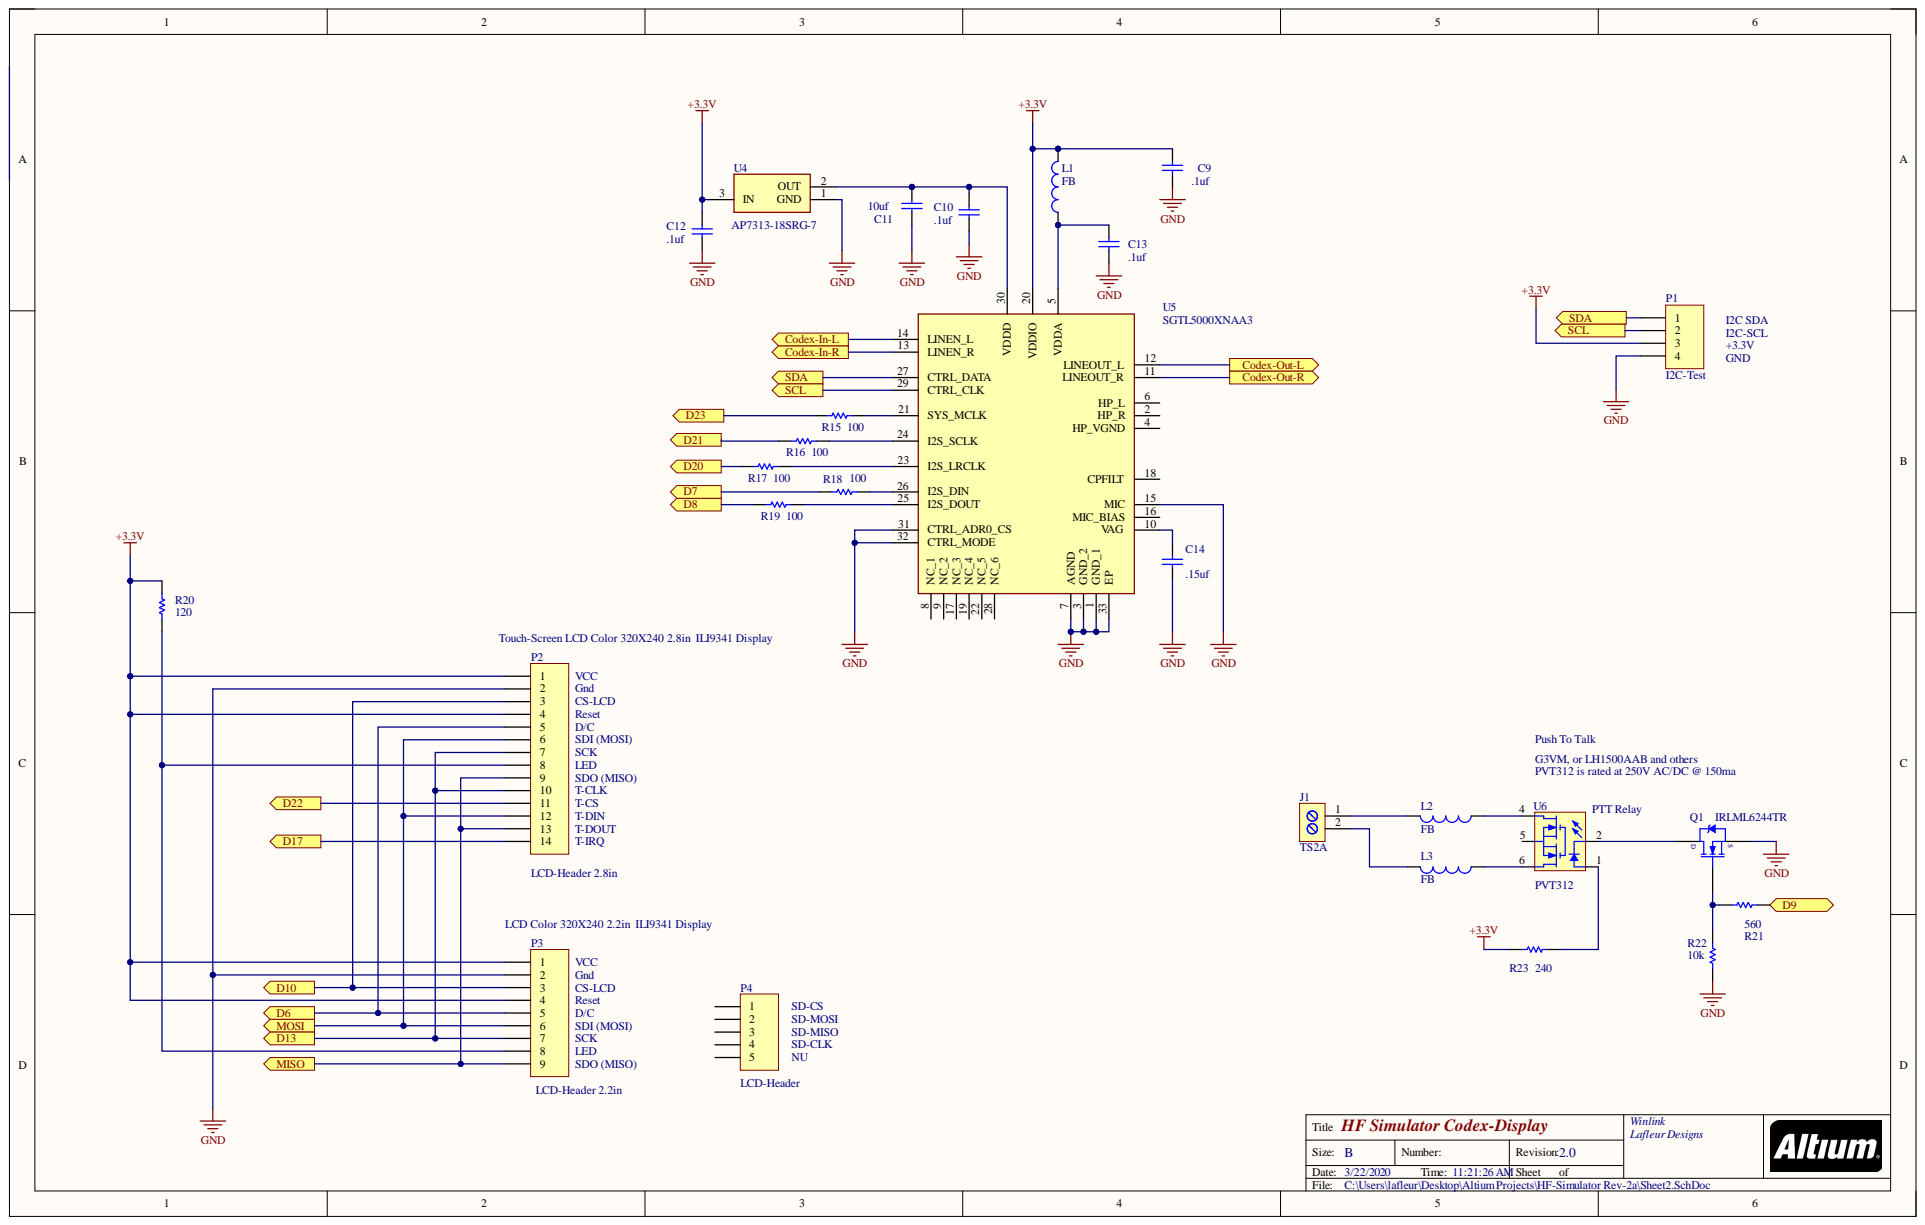
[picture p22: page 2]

Push To Talk
G3VM, or LH1500AAB and others
PVT312 is rated at 250V AC/DC @ 150ma

Title | Lafleur Designs F Simulator Codex-Display Winlink H

Size: B | Number: | Revision: 2.0
Date: 3/22/2020 Time: 11:21:26 AM | | Sheet of

C:\Users\lafleur\Desktop\AltiumProjects\HF-Simulator Rev-2a\Sheet2.SchDoc

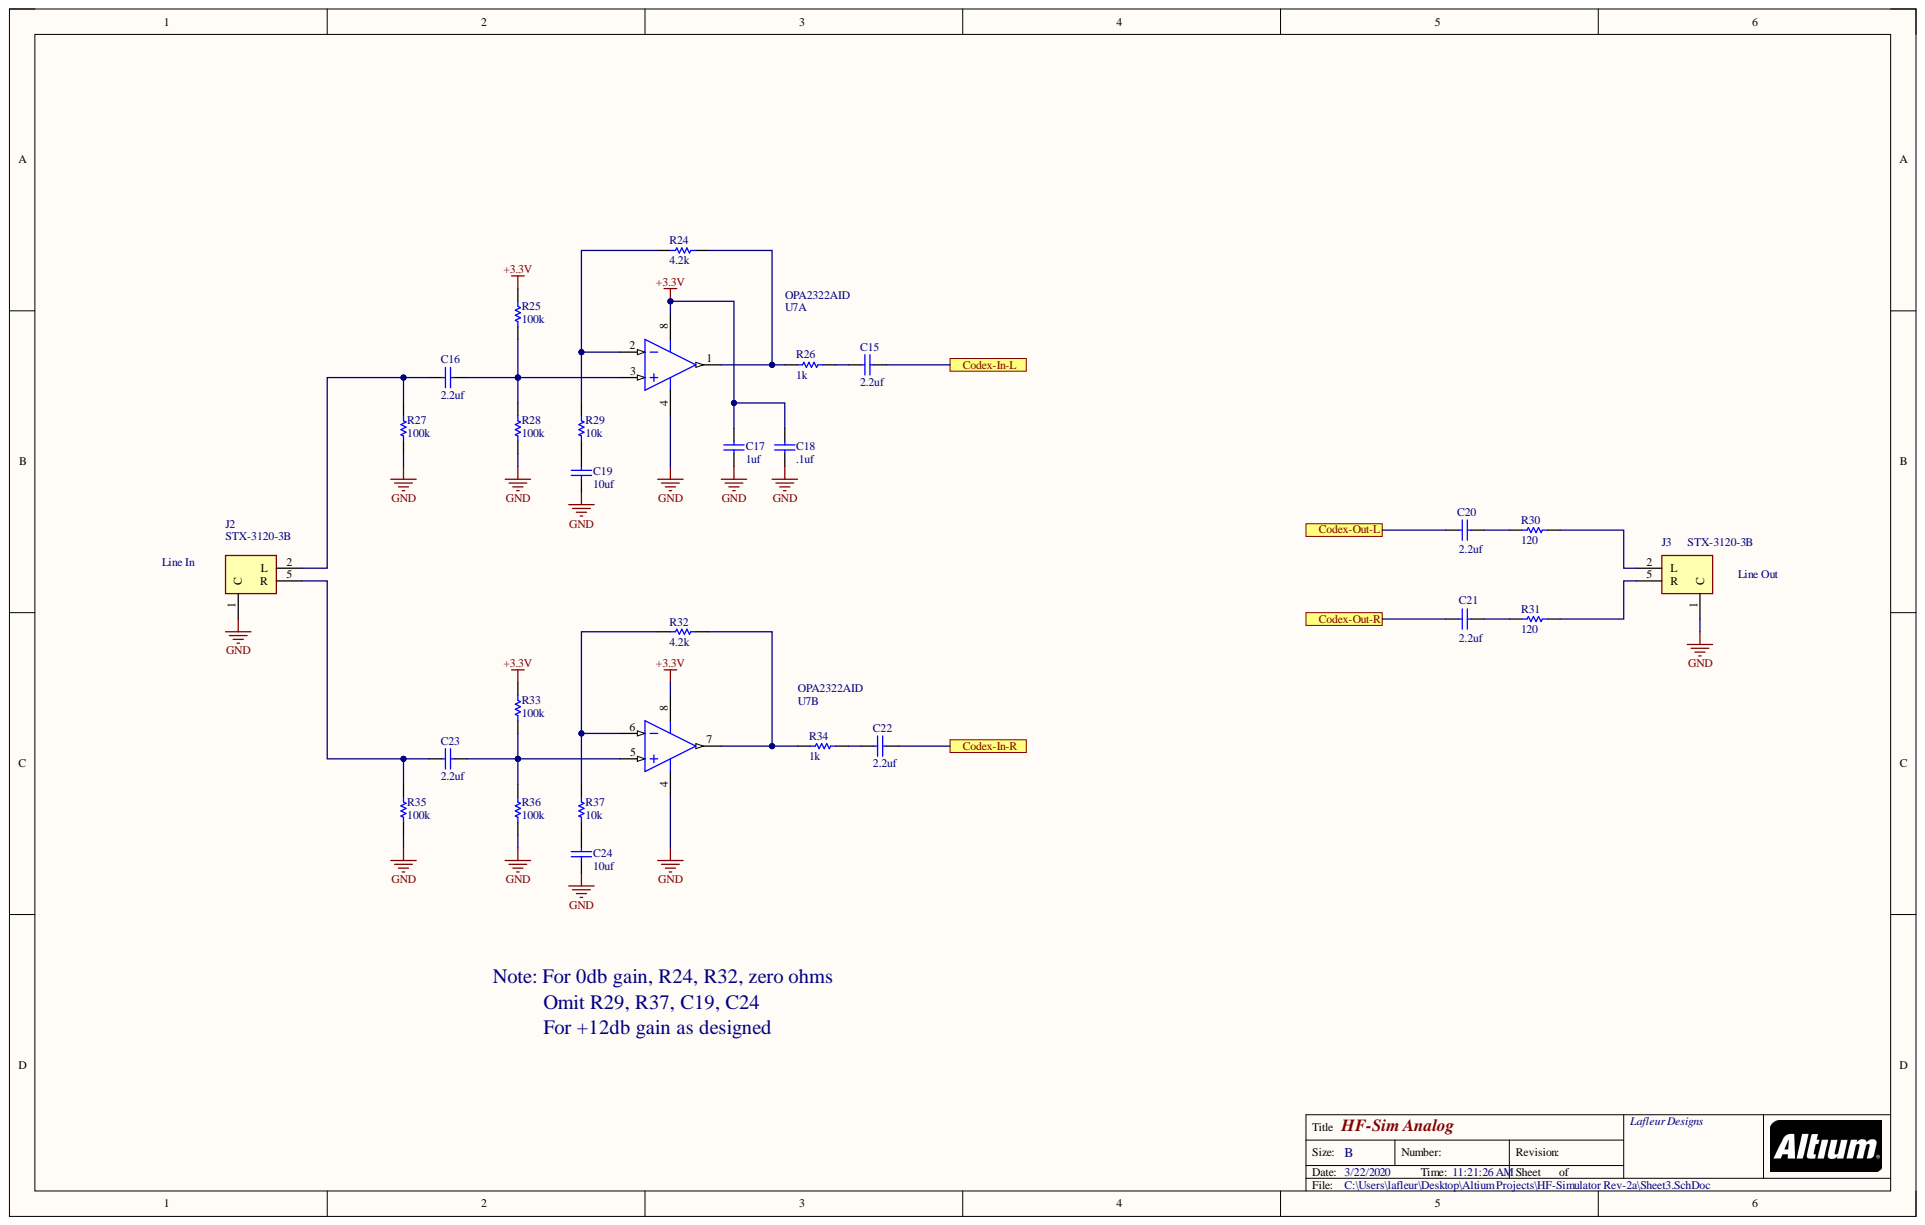
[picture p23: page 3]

Ti tl e H Lafleur F-Sim Analo g | Des igns

Si z e : B | N umber : | Revi s i on:
Dat e : 3/22/ 20 20 Ti me: 11:21:26 AM | | Sheet of
